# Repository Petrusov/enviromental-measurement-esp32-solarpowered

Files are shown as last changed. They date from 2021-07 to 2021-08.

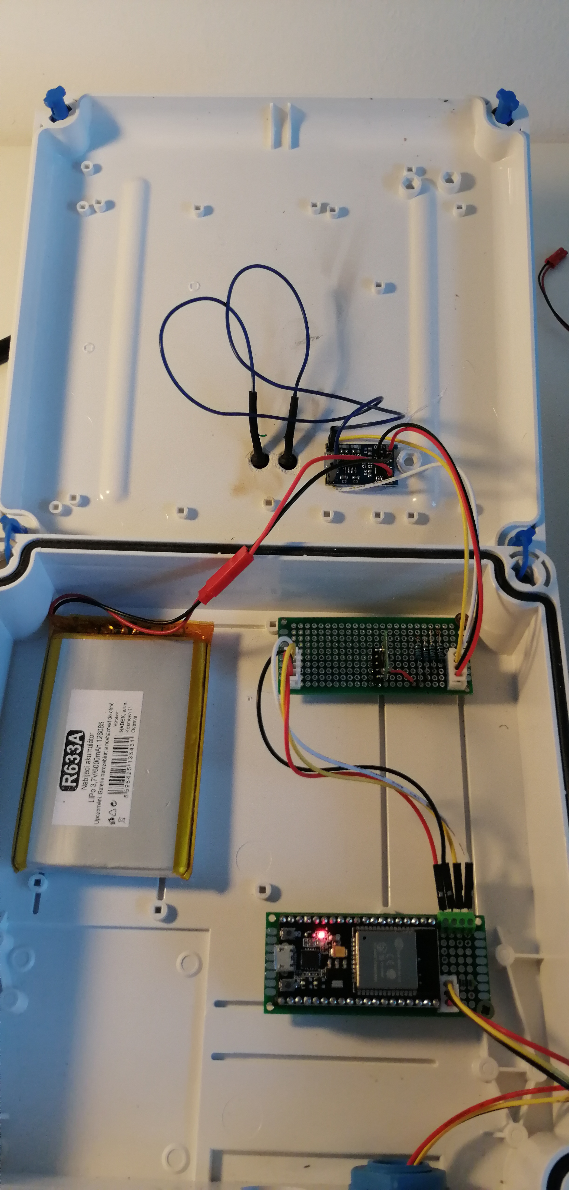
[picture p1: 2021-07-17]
Pictures/krabiceuvnitr_puvodniverze.jpg

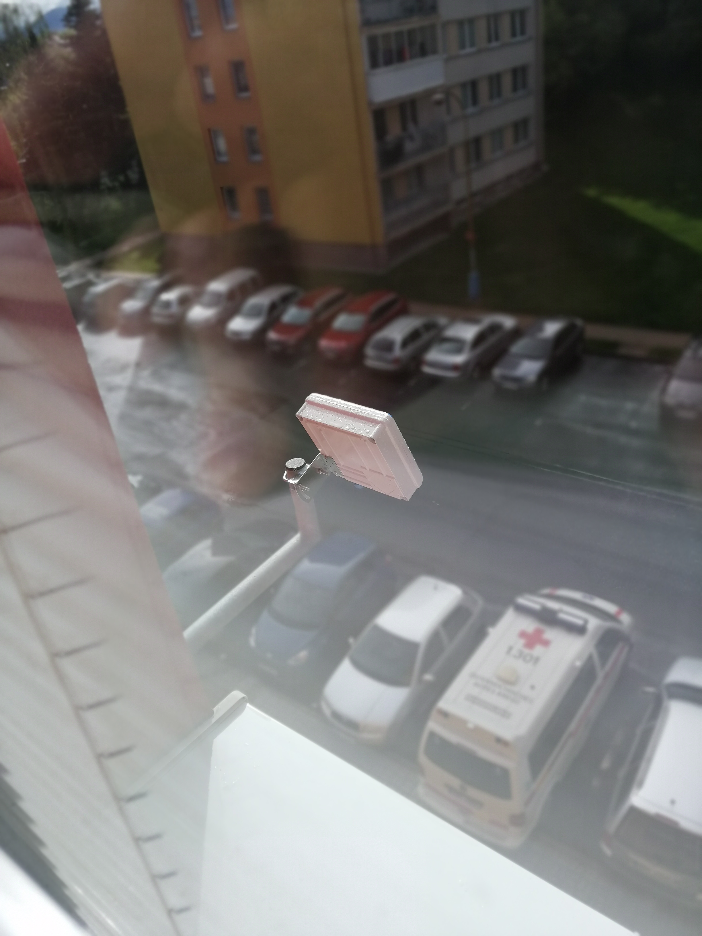
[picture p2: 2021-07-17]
Pictures/Krabicenastožáru.jpg

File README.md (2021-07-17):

# enviromental-measurement-esp32-solarpowered
This project was created due to the need to create the project as a bachelor's thesis.
The project is focused on the use of a microcontroller ESP32 for collecting data from sensors using communication buses. Data is published through MQTT messages to the MQTT server. Any MQTT client can remove data.

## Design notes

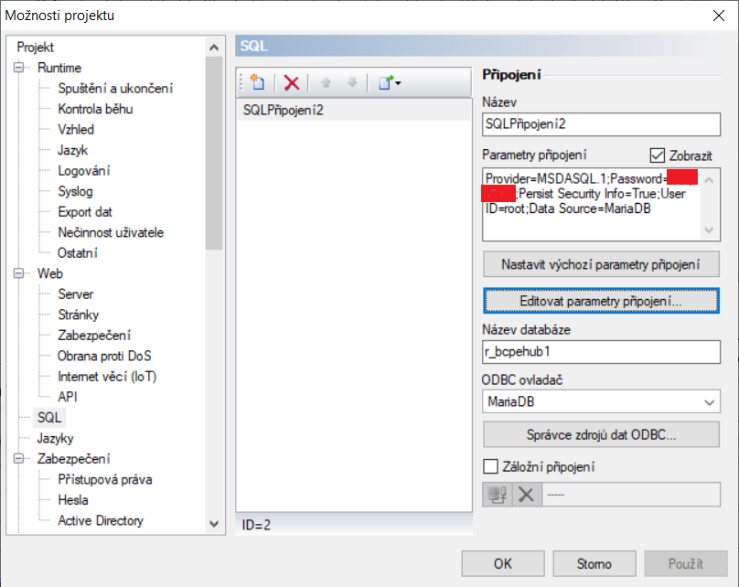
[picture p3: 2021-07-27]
Bitmaps/Reliance9.png

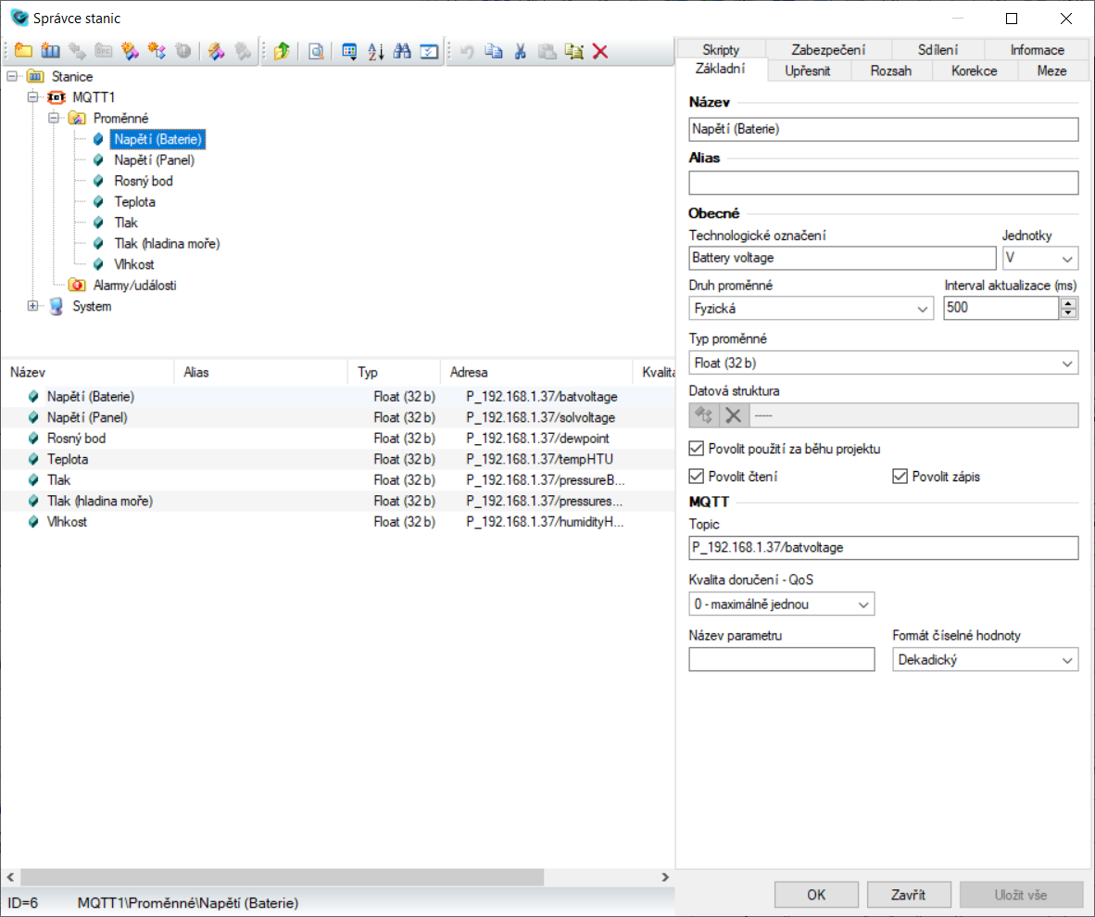
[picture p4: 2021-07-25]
Bitmaps/Reliance5.png

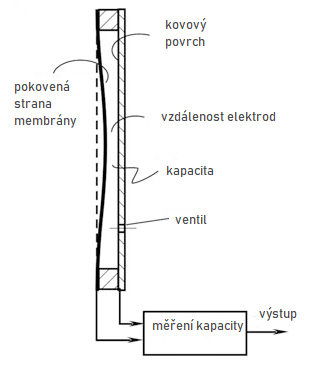
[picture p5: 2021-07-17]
Bitmaps/tlak_kapacitni_metoda.png

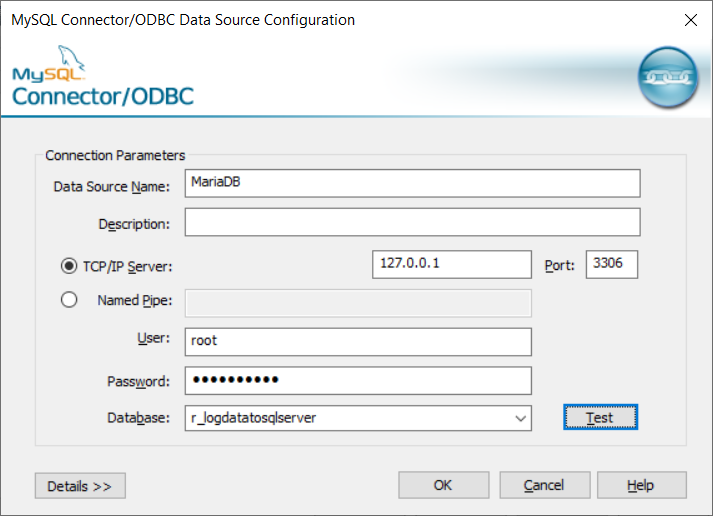
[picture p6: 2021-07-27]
Bitmaps/Reliance8.png

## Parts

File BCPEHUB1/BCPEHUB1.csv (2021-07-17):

Reference | Value | Footprint | Datasheet
R5 | 1k | Resistor_THT:R_Axial_DIN0204_L3.6mm_D1.6mm_P7.62mm_Horizontal
C2 | 0.1uF | Capacitor_THT:C_Disc_D3.8mm_W2.6mm_P2.50mm
D2 | LED | LED_THT:LED_D1.8mm_W3.3mm_H2.4mm
R6 | 1k | Resistor_THT:R_Axial_DIN0204_L3.6mm_D1.6mm_P7.62mm_Horizontal
D1 | LED | LED_THT:LED_D1.8mm_W3.3mm_H2.4mm
R7 | 10k | Resistor_THT:R_Axial_DIN0204_L3.6mm_D1.6mm_P7.62mm_Horizontal
R8 | 1k | Resistor_THT:R_Axial_DIN0204_L3.6mm_D1.6mm_P7.62mm_Horizontal
C4 | 0.1uF | Capacitor_THT:C_Radial_D10.0mm_H12.5mm_P5.00mm
R9 | 100 | Resistor_THT:R_Axial_DIN0204_L3.6mm_D1.6mm_P7.62mm_Horizontal
U2 | DW01 | DW01A:SOT23-6
U1 | TP4056 | lib:TP4056_SOP-8-PP
C3 | 10uF | Capacitor_THT:C_Radial_D10.0mm_H12.5mm_P5.00mm
U3 | FS8205A | FS8205A:SOP65P640X120-8N
U4 | ESP32-WROOM-32D | RF_Module:ESP32-WROOM-32 | https://www.espressif.com/sites/default/files/documentation/esp32-wroom-32d_esp32-wroom-32u_datasheet_en.pdf
R3 | 10k | Resistor_THT:R_Axial_DIN0204_L3.6mm_D1.6mm_P7.62mm_Horizontal | ~
R4 | 10k | Resistor_THT:R_Axial_DIN0204_L3.6mm_D1.6mm_P7.62mm_Horizontal | ~
R1 | 10k | Resistor_THT:R_Axial_DIN0204_L3.6mm_D1.6mm_P7.62mm_Horizontal | ~
R2 | 10k | Resistor_THT:R_Axial_DIN0204_L3.6mm_D1.6mm_P7.62mm_Horizontal | ~
J1 | Conn_01x02_Female | Connector_JST:JST_XH_B2B-XH-A_1x02_P2.50mm_Vertical | ~
C1 | 10uF | Capacitor_THT:CP_Radial_D4.0mm_P2.00mm | ~
J4 | Conn_01x02_Female | Connector_JST:JST_XH_B2B-XH-A_1x02_P2.50mm_Vertical | ~
J10 | Conn_01x05_Female | Connector_PinSocket_2.54mm:PinSocket_1x05_P2.54mm_Vertical | ~
R15 | 10k | Resistor_THT:R_Axial_DIN0204_L3.6mm_D1.6mm_P7.62mm_Horizontal | ~
J11 | Conn_01x04_Female | Connector_JST:JST_XH_B4B-XH-A_1x04_P2.50mm_Vertical | ~
J13 | Conn_01x04_Female | Connector_JST:JST_XH_B4B-XH-A_1x04_P2.50mm_Vertical | ~
J20 | Conn_01x03_Female | Connector_JST:JST_XH_B4B-XH-A_1x04_P2.50mm_Vertical | ~

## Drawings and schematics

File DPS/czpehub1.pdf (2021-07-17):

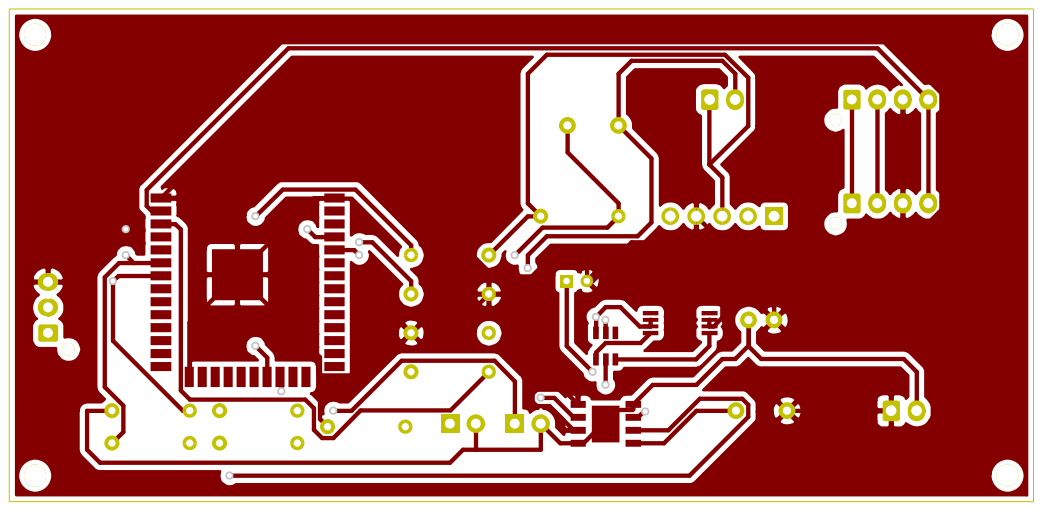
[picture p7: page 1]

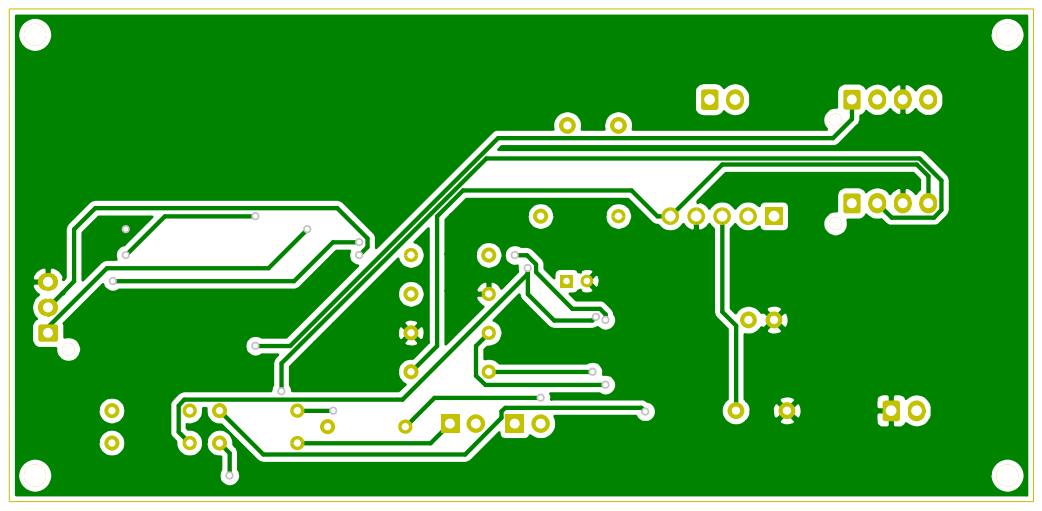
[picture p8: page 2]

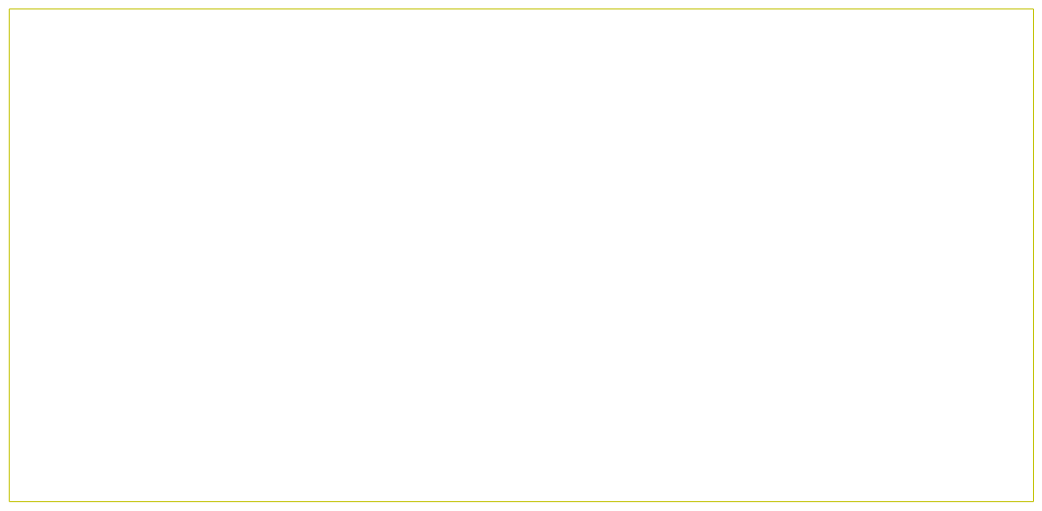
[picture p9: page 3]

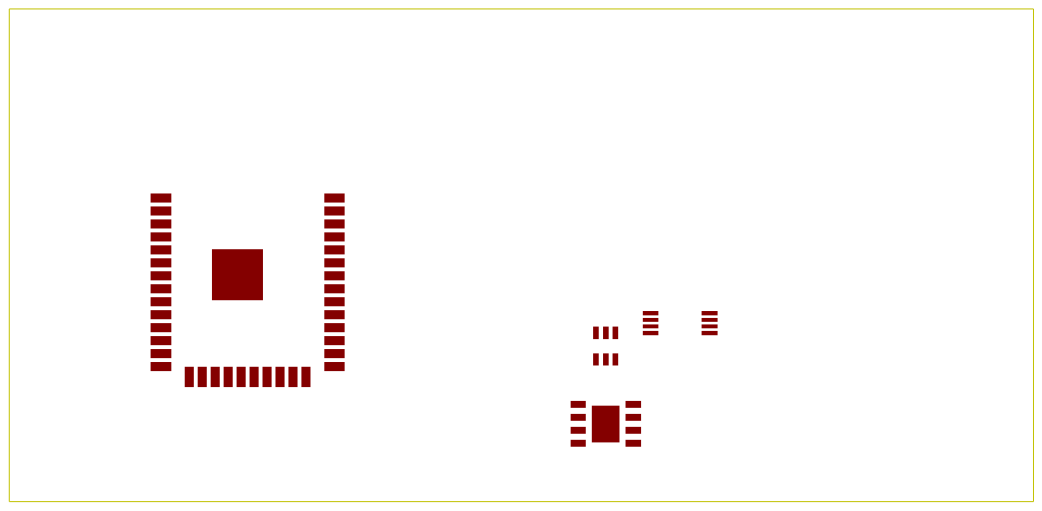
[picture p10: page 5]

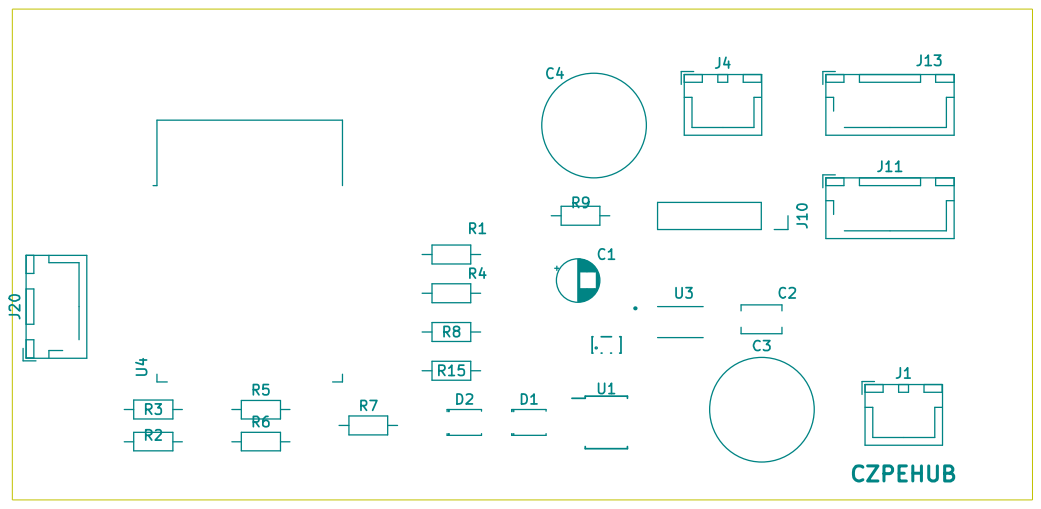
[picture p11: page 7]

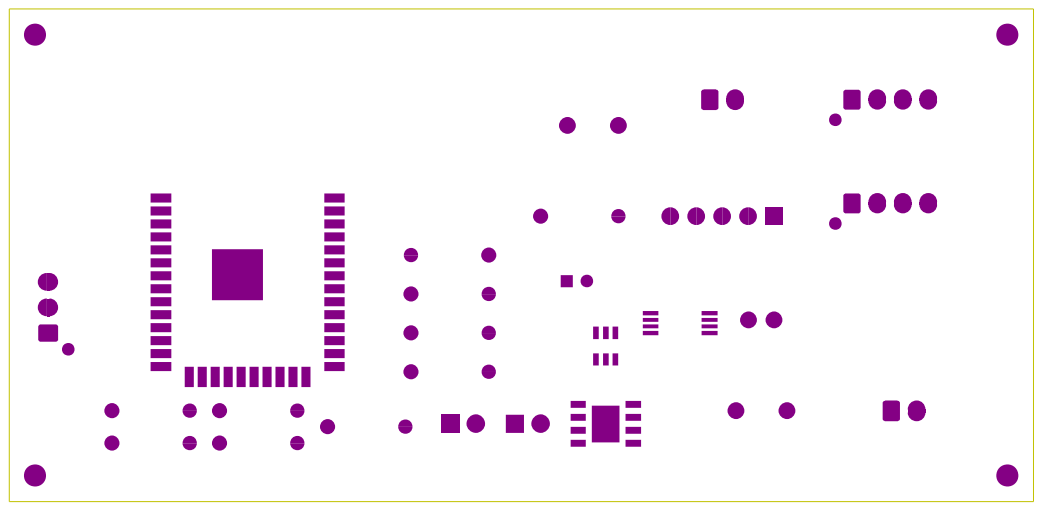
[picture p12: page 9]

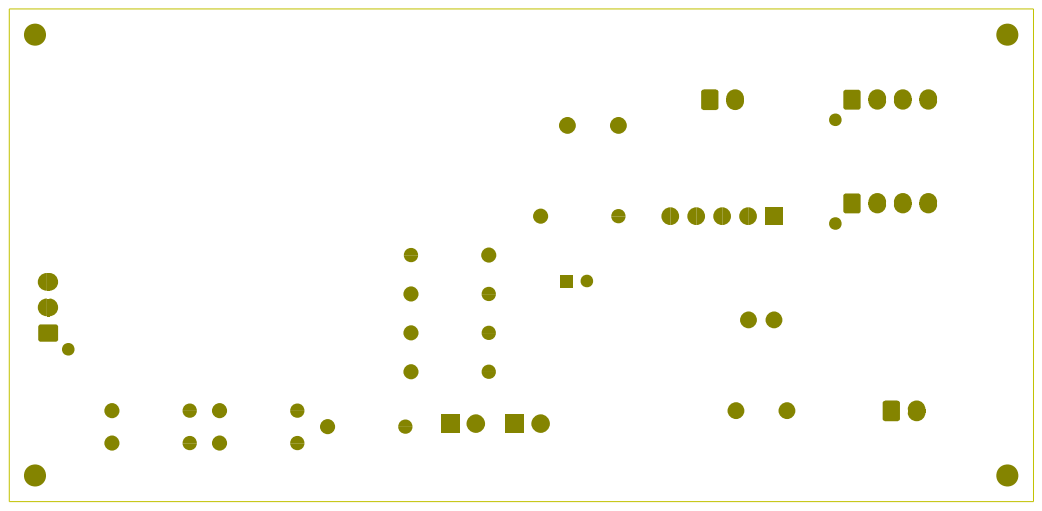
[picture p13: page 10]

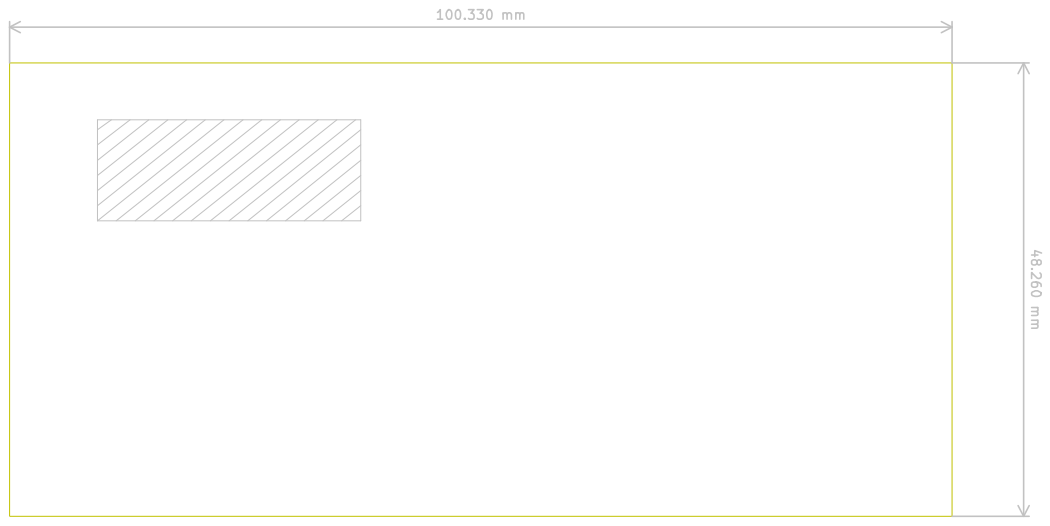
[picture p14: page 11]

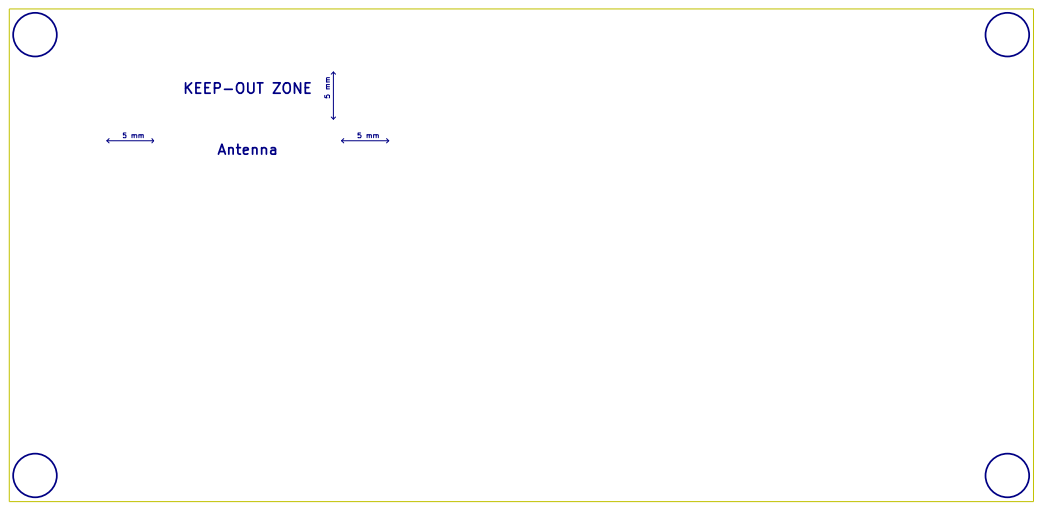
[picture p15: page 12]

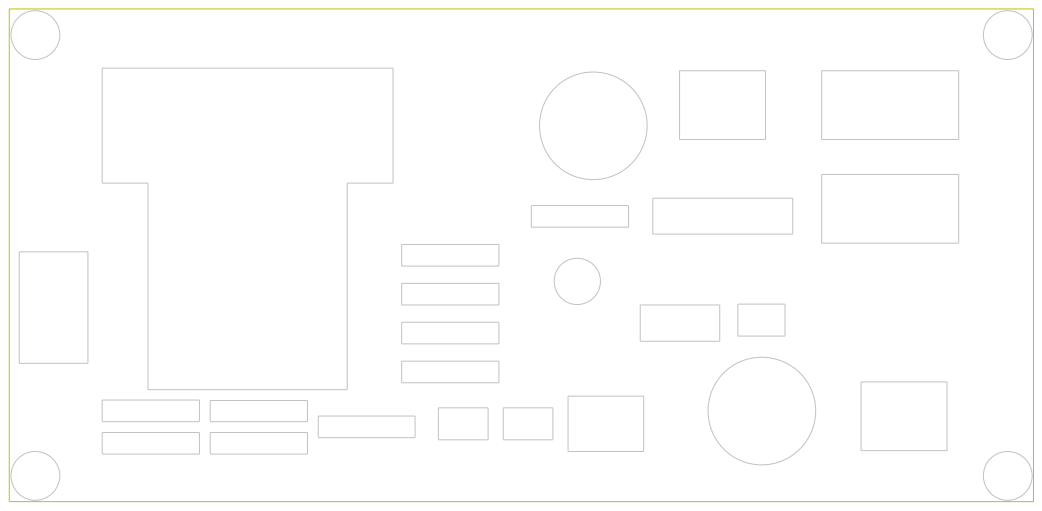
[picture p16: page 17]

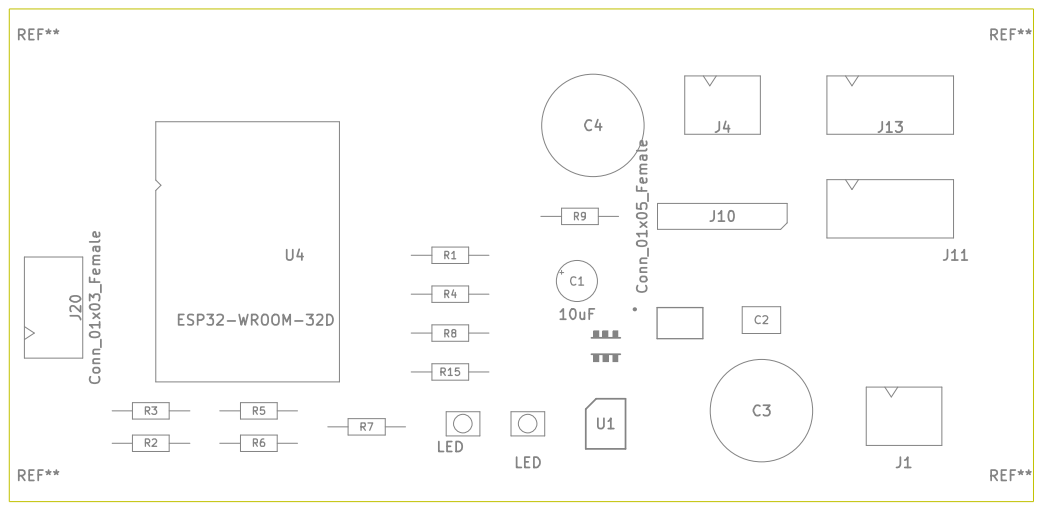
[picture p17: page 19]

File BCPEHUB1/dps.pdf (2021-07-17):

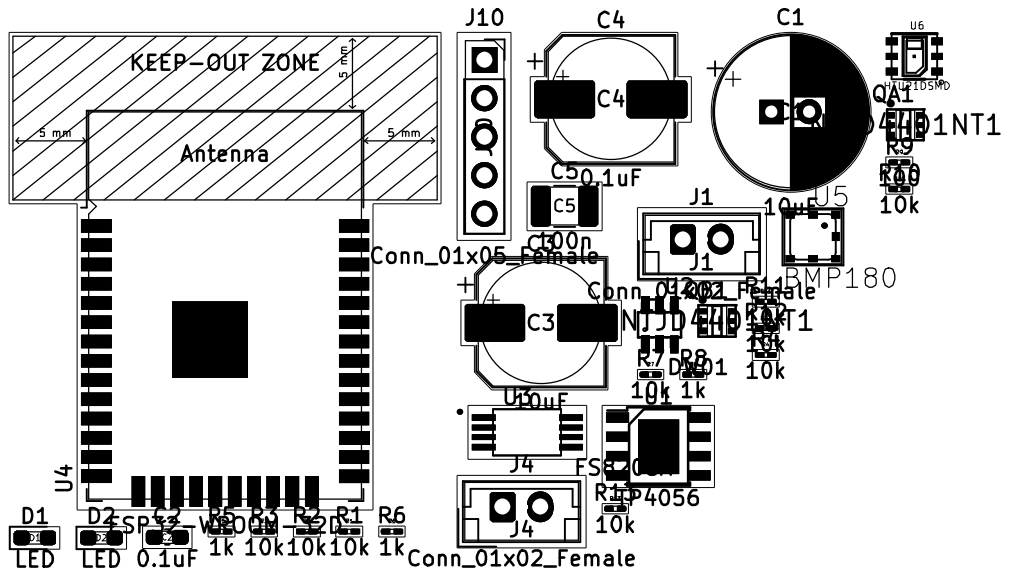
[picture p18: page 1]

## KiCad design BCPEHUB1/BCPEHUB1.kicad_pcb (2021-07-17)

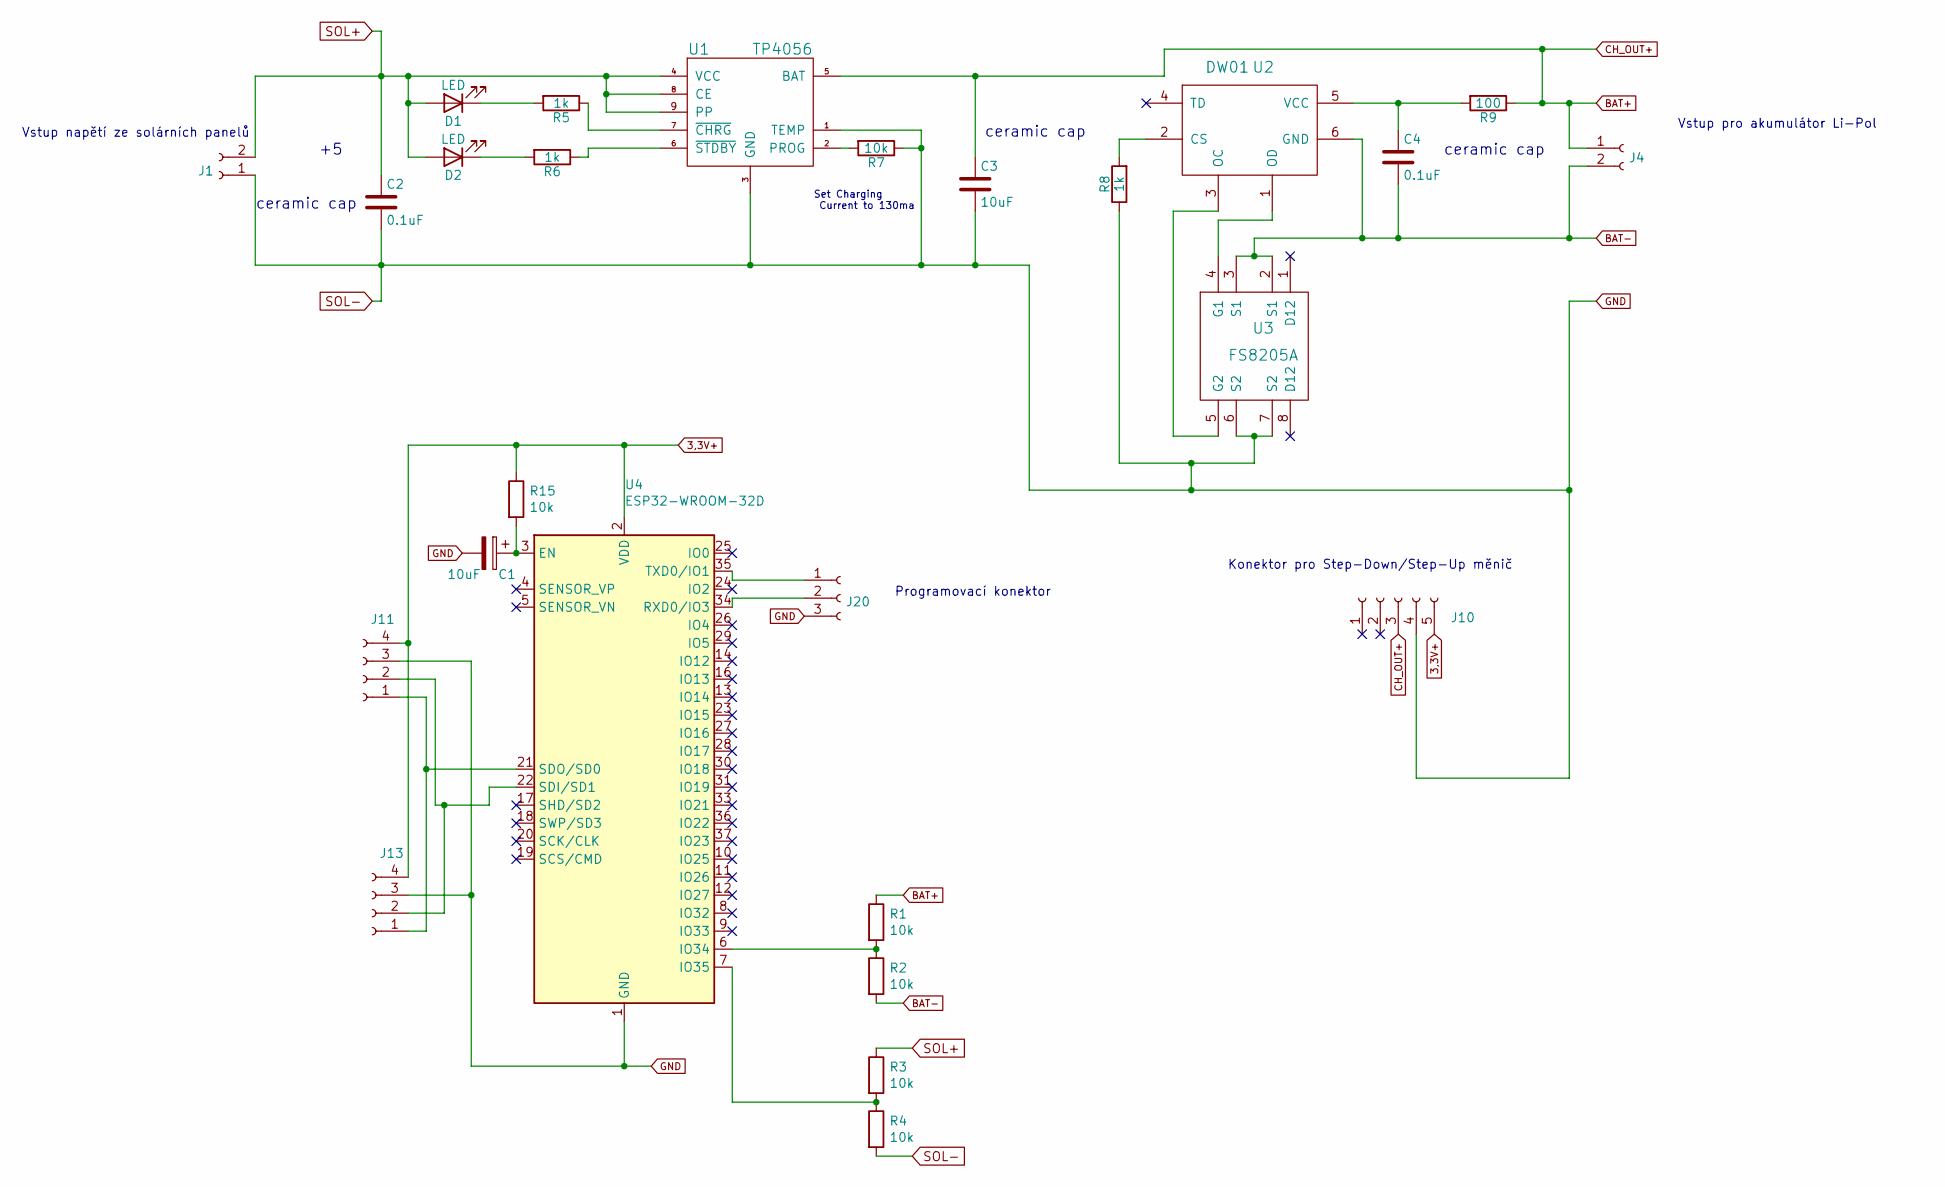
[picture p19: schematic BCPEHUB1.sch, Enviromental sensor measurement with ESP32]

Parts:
C1: 10uF; CP_Radial_D4.0mm_P2.00mm
C2: 0.1uF; C_Disc_D3.8mm_W2.6mm_P2.50mm
C3: 10uF; C_Radial_D10.0mm_H12.5mm_P5.00mm
C4: 0.1uF; C_Radial_D10.0mm_H12.5mm_P5.00mm
D1, D2: LED; LED_D1.8mm_W3.3mm_H2.4mm
J1, J4: Conn_01x02_Female; JST_XH_B2B-XH-A_1x02_P2.50mm_Vertical
J10: Conn_01x05_Female; PinSocket_1x05_P2.54mm_Vertical
J11, J13: Conn_01x04_Female; JST_XH_B4B-XH-A_1x04_P2.50mm_Vertical
J20: Conn_01x03_Female; JST_XH_B4B-XH-A_1x04_P2.50mm_Vertical
R1, R2, R3, R4, R7, R15: 10k; R_Axial_DIN0204_L3.6mm_D1.6mm_P7.62mm_Horizontal
R5, R6, R8: 1k; R_Axial_DIN0204_L3.6mm_D1.6mm_P7.62mm_Horizontal
R9: 100; R_Axial_DIN0204_L3.6mm_D1.6mm_P7.62mm_Horizontal
U1: TP4056; TP4056_SOP-8-PP
U2: DW01; SOT23-6
U3: FS8205A; SOP65P640X120-8N
U4: ESP32-WROOM-32D; ESP32-WROOM-32

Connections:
3,3V+: J10.5, J11.4, J13.4, R15.1, U4.2 (VDD)
BAT+: C3.1, J4.1, J10.3, R1.1, R9.1, U1.5 (BAT)
BAT-: C4.2, J4.2, R2.2, U2.6 (GND), U3.2 (S1), U3.3 (S1)
GND: C1.2, C2.2, C3.2, J1.1, J10.4, J11.3, J13.3, J20.3, R4.2, R7.1, R8.1, U1.1 (TEMP), U1.3 (GND), U3.6 (S2), U3.7 (S2), U4.1 (GND), U4.15 (GND), U4.38 (GND), U4.39 (GND)
unnamed: C1.1, R15.2, U4.3 (EN)
unnamed: C4.1, R9.2, U2.5 (VCC)
unnamed: D1.1 (K), R5.2
unnamed: D2.1 (K), R6.2
unnamed: J11.1, J13.1, U4.21 (SDO/SD0)
unnamed: J11.2, J13.2, U4.22 (SDI/SD1)
unnamed: J20.1, U4.35 (TXD0/IO1)
unnamed: J20.2, U4.34 (RXD0/IO3)
unnamed: R1.2, R2.1, U4.6 (IO34)
unnamed: R3.2, R4.1, U4.7 (IO35)
unnamed: R5.1, U1.7 (~CHRG)
unnamed: R6.1, U1.6 (~STDBY)
unnamed: R7.2, U1.2 (PROG)
unnamed: R8.2, U2.2 (CS)
unnamed: U2.1 (OD), U3.4 (G1)
unnamed: U2.3 (OC), U3.5 (G2)
SOL+: C2.1, D1.2 (A), D2.2 (A), J1.2, R3.1, U1.4 (VCC), U1.8 (CE), U1.9 (PP)

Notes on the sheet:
Set Charging Current to 130ma
ceramic cap
Konektor pro Step-Down/Step-Up měnič
Vstup napětí ze solárních panelů
Vstup pro akumulátor Li-Pol
Programovací konektor

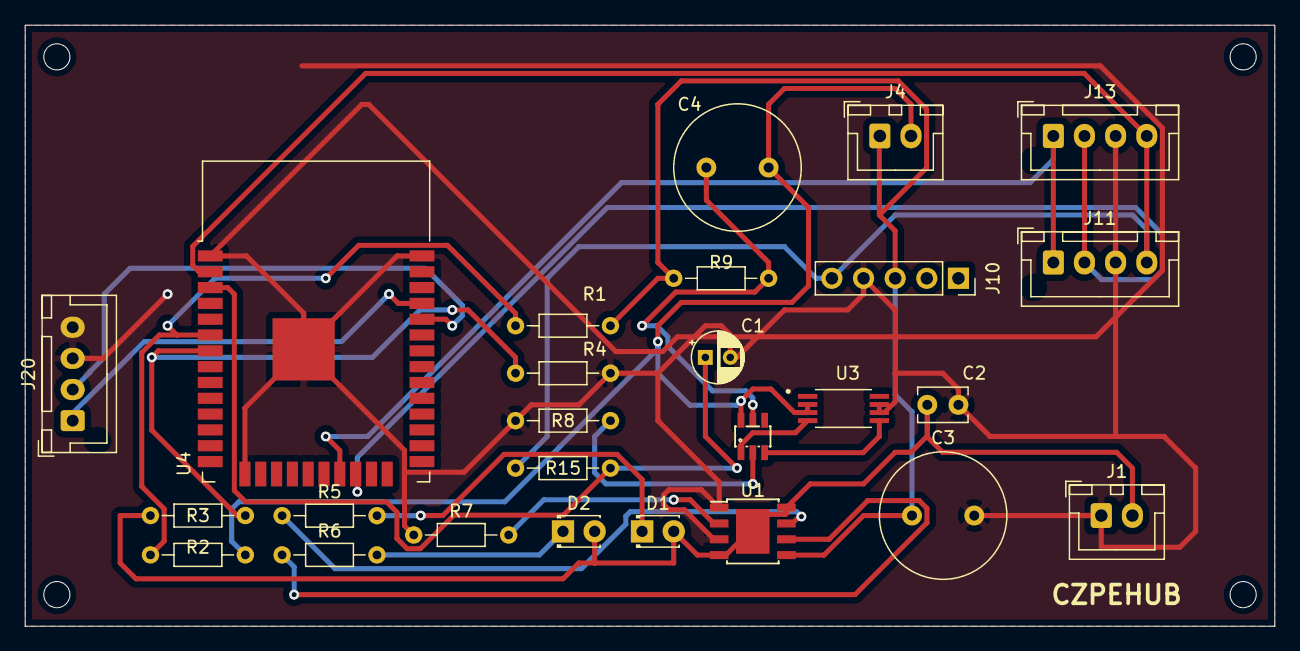
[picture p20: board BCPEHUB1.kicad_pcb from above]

Board: 2 copper layers, 100.3 x 48.3 mm, 26 parts (0 on the bottom side), 21 nets.

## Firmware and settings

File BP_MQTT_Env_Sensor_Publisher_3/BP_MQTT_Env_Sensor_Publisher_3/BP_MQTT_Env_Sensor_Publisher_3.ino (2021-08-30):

//Bakalářský projekt  - měření enviromentálních veličin jako jsou teplota, atmosférická vlhkost, tlak a koncentrace plynů
//----------------------------------------------------------------------------------------------------------------------------------
//Knihovna pro WIFI a MQTT
#include <WiFi.h>
#include <PubSubClient.h>
#include <Wire.h>

//Knihovna pro BMP180
#include <Adafruit_BMP085.h>

//Knihovna pro HTU21D
#include <SparkFunHTU21D.h>


// Zde se definuje přepočet s na us, pro funkci deep sleep
uint64_t uS_TO_S_FACTOR = 1000000; 
// 10 minut = 600 sekund
uint64_t TIME_TO_SLEEP = 600; 

// Připojení k Wifi
const char* ssid = "SSID";
const char* password = "password";

// Adresa MQTT Brokeru:
//const char* mqtt_server = "192.168.1.9";
const char* mqtt_server = "192.168.1.9";

WiFiClient espClient;
PubSubClient client(espClient);
long lastMsg = 0;
char msg[50];
int value = 0;

int BatValue = 0;
int SolarValue = 0;
float BatVoltage = 0;
float SolarVoltage = 0;
const int BAT = 34;
const int SOL = 35;
int korekce = 22;

float tempBMP;
float pressureBMP;
float altitudeBMP;
float tempHTU;
float humiHTU;
double dewpoint;
double dewp;


//BMP180 definice
Adafruit_BMP085 senzorBMP;

//HTU21D definice
HTU21D senzorHTU;

void setup() {
  // Spustí sériovou konzoli pro výpis
  Serial.begin(115200);

setup_wifi();
  client.setServer(mqtt_server, 1883);
//  client.setCallback(callback);

senzorHTU.begin();

if (!senzorBMP.begin()) {
  Serial.println("Nemohu najít BMP180 senzor!");
  while (1) {}
}

if (!client.connected()) {
    reconnect();
  }
  client.loop();

// Napětí
   getBatVoltage();
   
    // Convert the value to a char array
    char BatVoltString[8];
    dtostrf(BatVoltage, 1, 2, BatVoltString);
    Serial.print("Napětí baterie (upravené): ");
    Serial.println(BatVoltString);
    client.publish("esp32/batvoltage", BatVoltString);

    getSolarVoltage();
    
    // Convert the value to a char array
    char SolString[8];
    dtostrf(SolarVoltage, 1, 2, SolString);
    Serial.print("Napětí panelu (upravené): ");
    Serial.println(SolString);
    client.publish("esp32/solvoltage", SolString);

//Teplota, tlak, výška BMP
    getBMPreadings();
    // Convert the value to a char array
    char BMPString[8];

    dtostrf(pressureBMP, 1, 2, BMPString);
    Serial.print("Tlak BMP: ");
    Serial.println(BMPString);
    client.publish("esp32/pressureBMP", BMPString);
/*    
    dtostrf(altitudeBMP, 1, 2, BMPString);
    Serial.print("Výška BMP: ");
    Serial.println(BMPString);
    client.publish("esp32/altitudeBMP", BMPString);
*/
//Teplota, vlhkost HTU
    getHTUreadings();
    // Convert the value to a char array
    char HTUString[8];
    dtostrf(tempHTU, 1, 2, HTUString);
    Serial.print("Teplota HTU: ");
    Serial.println(HTUString);
    client.publish("esp32/tempHTU", HTUString);
    
    dtostrf(humiHTU, 1, 2, HTUString);
    Serial.print("Vlhkost HTU: ");
    Serial.println(HTUString);
    client.publish("esp32/humidityHTU", HTUString);

    calcDefPoint(tempDS, humiHTU);
   Serial.println(dewpoint);
    char DPString[8];
    dtostrf(dewpoint, 5, 2, DPString);
    Serial.print("Rosný bod: ");
    Serial.println(DPString);
    client.publish("esp32/dewpoint", DPString);
  
  // Vše provedeno, aktivuje se deep sleep, odečítá se čas od startu programu
  
   delay(500);
 // Serial.print("Čas: ");Serial.println(myTime);
  
  Serial.println("Vše vyčteno a publikováno a teď jdu spát");
  unsigned long myTime = millis();
  esp_sleep_enable_timer_wakeup(TIME_TO_SLEEP * uS_TO_S_FACTOR - myTime);
  esp_bt_controller_disable();
  
  esp_deep_sleep_start(); 
}

void loop() {
  // nikdy se sem program nedostane, protože ESP32 usne
}

void setup_wifi() {
  delay(10);
  // Připojení k WIFI (nutné)
  Serial.println();
  Serial.print("Připojen k: ");
  Serial.println(ssid);

  WiFi.begin(ssid, password);

  while (WiFi.status() != WL_CONNECTED) {
    delay(500);
    Serial.print(".");
  }

  Serial.println("");
  Serial.println("WiFi připojena");
  Serial.println("IP adresa: ");
  Serial.println(WiFi.localIP());
}

void reconnect() {
  // 
  while (!client.connected()) {
    Serial.println("Pokus o připojení k MQTT Brokeru");
    // Pokus o připojení
    if (client.connect("ESP8266Client")) {
      Serial.println("připojen...");
      // Subscribe (pro případné povely)
      client.subscribe("esp32/output");
    } else {
      Serial.print("failed, rc=");
      Serial.print(client.state());
      Serial.println(" pokus o připojení za 5 sekund");
      delay(5000);
    }
  }
} 

void getBatVoltage(){
  BatValue = analogRead(BAT);
  BatVoltage = BatValue * (7.12 / 4095.0);
  Serial.print("Napětí: ");
  Serial.println(BatVoltage);
  Serial.print("Hodnota vstupu: ");
  Serial.println(BatValue);
}

void getSolarVoltage(){
  SolarValue = analogRead(SOL);
  SolarVoltage = SolarValue * (7.12 / 4095.0);
  Serial.print("Napětí na vstupu sol.panelu: ");
  Serial.println(SolarVoltage);
  Serial.print("Hodnota U solárního panelu: ");
  Serial.println(SolarValue);
}

void getBMPreadings(){
 // tempBMP = senzorBMP.readTemperature(); 
  pressureBMP =  (senzorBMP.readPressure()+korekce*100)/100;
//  altitudeBMP =  senzorBMP.readAltitude();
/*  Serial.print("Teplota BMP: ");
  Serial.print(tempBMP);
*/  Serial.print("Tlak BMP: ");
  Serial.print(pressureBMP);
 /* Serial.print("Výška BMP: ");
  Serial.print(altitudeBMP);
 */ 
 }

 void getHTUreadings(){
 // tempHTU = senzorHTU.readTemperature(); 
  humiHTU =  senzorHTU.readHumidity();
 
/*  Serial.print("Teplota HTU: ");
  Serial.print(tempHTU);
*/  
  Serial.print("Vlhkost (relativní): ");
  Serial.print(humiHTU);
 }

  void calcDefPoint(float tempDS, float humiHTU){
  double gamma = log(humiHTU / 100) + ((17.62 * tempDS) / (243.5 + tempDS));
  double dewpoint = 243.5 * gamma / (17.62 - gamma);
 
  Serial.print("Rosný bod: ");
  Serial.println(dewpoint);
  char DPString[8];
    dtostrf(dewpoint, 5, 2, DPString);
    Serial.print("Rosný bod: ");
    Serial.println(DPString);
    client.publish("esp32/dewpoint", DPString);
 }
